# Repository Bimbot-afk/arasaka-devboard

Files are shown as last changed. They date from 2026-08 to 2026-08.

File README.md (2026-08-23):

# Arasaka DevBoard

A custom development board hardware project designed in KiCad.
It has a cool design based on Arasaka from Cyberpunk 2077 >:D

## Hardware Specifications & BOM

The board is built around the RP2040 ecosystem using high-density SMD components (mostly 0402 imperial footprint).

*   **Microcontroller (MCU):** Raspberry Pi RP2040 (Dual ARM Cortex-M0+ @ 133MHz, QFN-56)
*   **Storage:** Winbond W25Q128JVSIQ (16MB SPI Flash, SOIC-8)
*   **Power Management:** onsemi NCP1117ST33T3G (3.3V LDO Linear Regulator, SOT-223)
*   **Clock / Timing:** YXC 12MHz Crystal Oscillator (SMD 3225-4P)
*   **Interfacing:** Korean Hroparts TYPE-C-31-M-12 (USB-C Receptacle, 16-pin SMD)
*   **Electromechanical:** ALPS SKRKAEE020 (Tactile Switch for BOOTSEL/RESET)
*   **Passives:** Standard 0402 and 0603 ceramic capacitors (X5R/X7R dielectrics) and thick film resistors (1% tolerance on USB data lines).
*   **Expansion:** 2.54mm pitch through-hole pin headers.

## Schematics

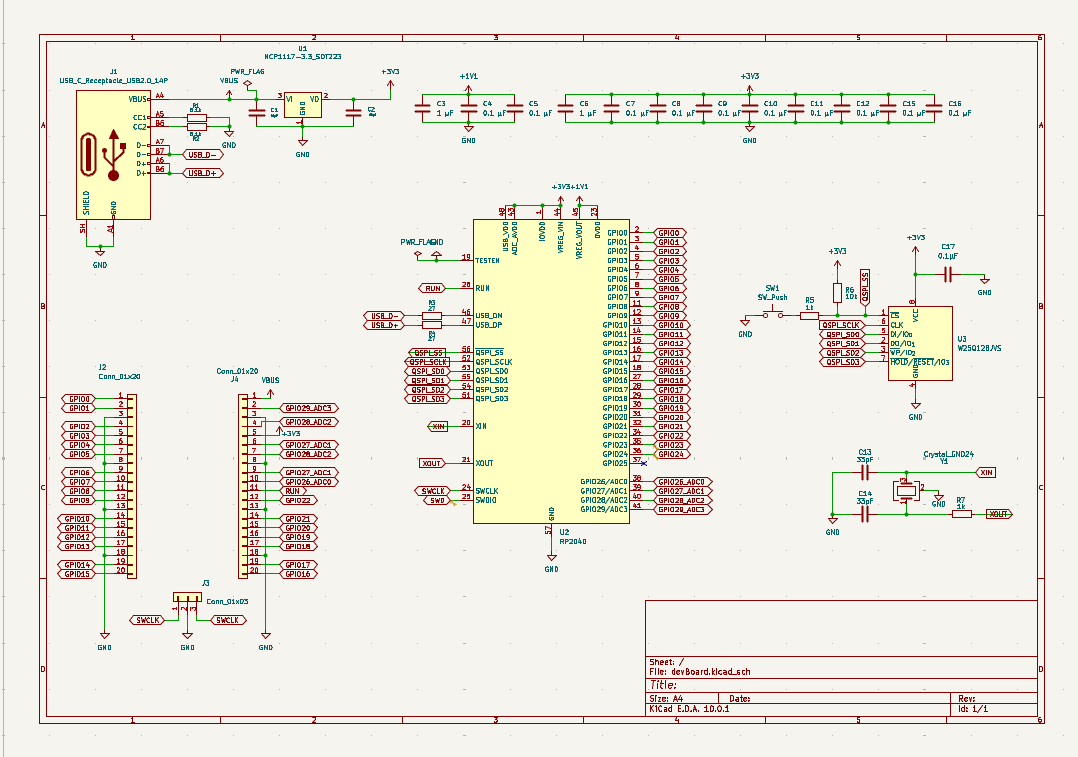
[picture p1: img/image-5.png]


## Layers

### F.cu

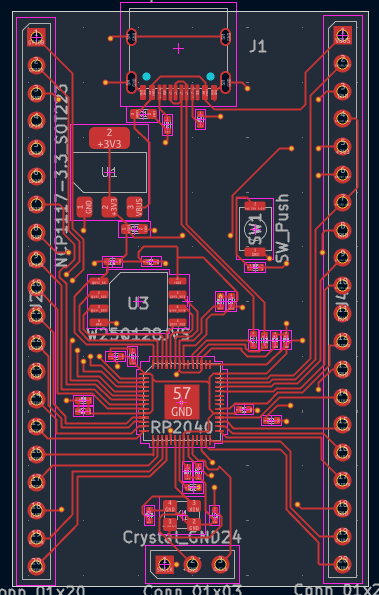
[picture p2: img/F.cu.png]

### B.cu

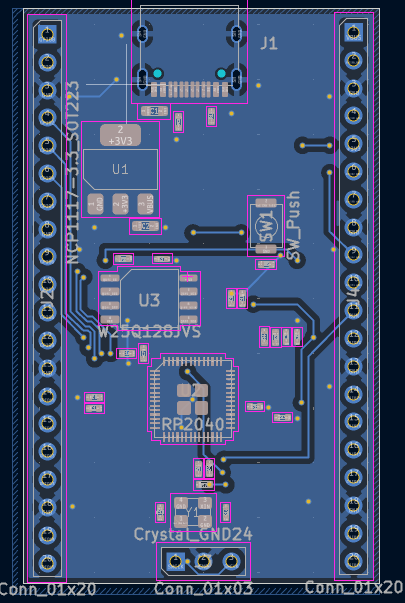
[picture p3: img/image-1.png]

### Both

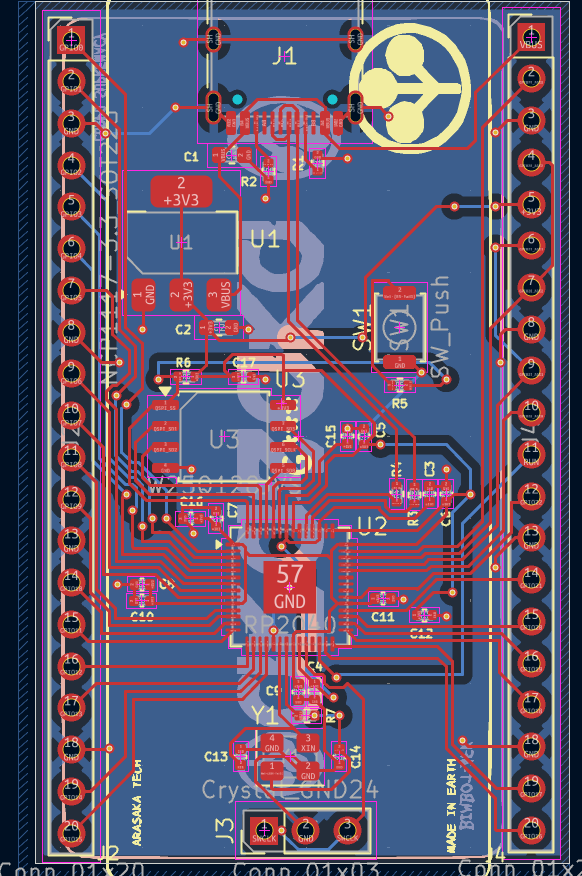
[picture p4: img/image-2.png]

### Front
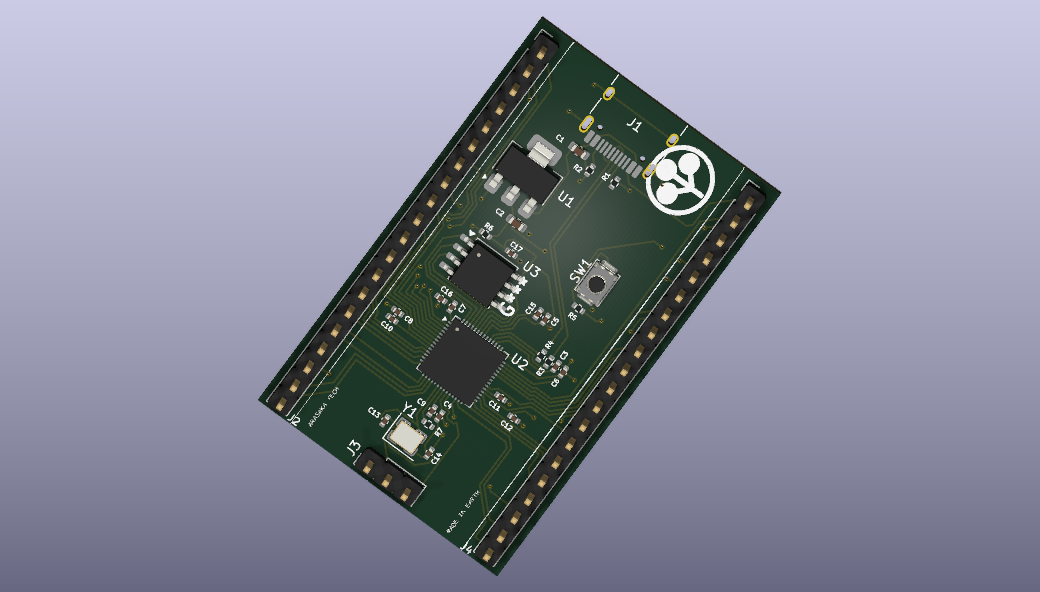
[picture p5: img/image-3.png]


### BACK
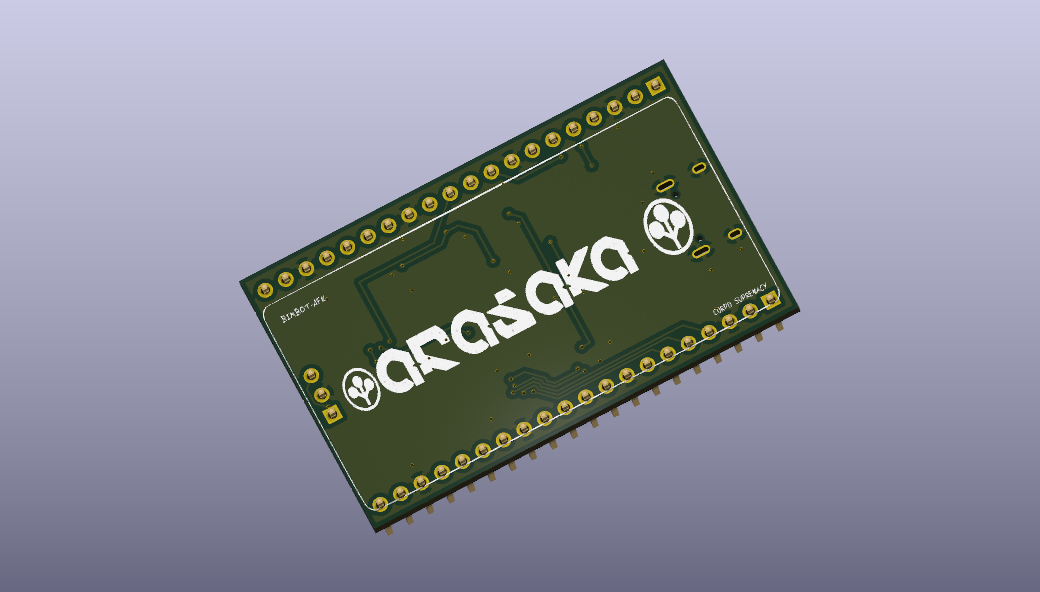
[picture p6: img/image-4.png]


## Project Structure

- **`3D_Models/`**: Contains 3D assets (`.step`, `.glb`, `.blend`) for the board and components.
- **`Fabrication/`**: Destination folder for generated manufacturing files like Gerbers, drill files, and BOMs.
- **`Libraries/`**: Project-specific footprints and symbols (e.g., custom Arasaka assets).
- **Core Files**: The main KiCad project files (`.kicad_pro`, `.kicad_sch`, `.kicad_pcb`) are located in the root directory.

## Getting Started

To view or modify this project, you will need [KiCad](https://www.kicad.org/) (Version 6+ recommended). 

1. Clone this repository.
2. Open the `devBoard.kicad_pro` file in KiCad to load the project.

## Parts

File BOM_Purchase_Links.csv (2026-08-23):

Designator | Value | Footprint | Quantity | Part Number | Purchase Link
C1, C2 | 10uF | 0603 | 2 | Generic 10uF 0603 | https://www.lcsc.com/search?q=10uF%200603%2010V
C3, C6 | 1uF | 0402 | 2 | Generic 1uF 0402 | https://www.lcsc.com/search?q=1uF%200402%2010V
C4, C5, C7, C8, C9, C10, C11, C12, C15, C16, C17 | 0.1uF | 0402 | 11 | Generic 0.1uF 0402 | https://www.lcsc.com/search?q=0.1uF%200402%2016V
C13, C14 | 33pF | 0402 | 2 | Generic 33pF 0402 | https://www.lcsc.com/search?q=33pF%200402%2050V
J1 | USB-C 16-pin | TYPE-C-31-M-12 | 1 | HRO TYPE-C-31-M-12 | https://www.lcsc.com/product-detail/USB-Connectors_HRO-Han-Run-TYPE-C-31-M-12_C165948.html
J2, J4 | Header 1x20 | 2.54mm Vertical | 2 | Generic 1x20 Pin Header | https://www.lcsc.com/search?q=1x20%20pin%20header%202.54mm
J3 | Header 1x3 | 2.54mm Vertical | 1 | Generic 1x3 Pin Header | https://www.lcsc.com/search?q=1x3%20pin%20header%202.54mm
R1, R2 | 5.1k | 0402 | 2 | Generic 5.1k 1% 0402 | https://www.lcsc.com/search?q=5.1k%200402%201%25
R3, R4 | 27R | 0402 | 2 | Generic 27R 1% 0402 | https://www.lcsc.com/search?q=27R%200402%201%25
R5, R7 | 1k | 0402 | 2 | Generic 1k 1% 0402 | https://www.lcsc.com/search?q=1k%200402%201%25
R6 | 10k | 0402 | 1 | Generic 10k 1% 0402 | https://www.lcsc.com/search?q=10k%200402%201%25
SW1 | Tactile Switch | ALPS SKRK | 1 | ALPS SKRKAEE020 | https://www.lcsc.com/product-detail/Tactile-Switches_ALPS-Alpine-SKRKAEE020_C139797.html
U1 | 3.3V LDO | SOT-223 | 1 | NCP1117ST33T3G | https://www.lcsc.com/product-detail/Linear-Voltage-Regulators-LDO_onsemi-NCP1117ST33T3G_C6186.html
U2 | RP2040 MCU | QFN-56 | 1 | Raspberry Pi RP2040 | https://www.lcsc.com/product-detail/Microcontroller-Units-MCUs-MPUs-SOCs_Raspberry-Pi-RP2040_C2040.html
U3 | 16MB Flash | SOIC-8 | 1 | W25Q128JVSIQ | https://www.lcsc.com/product-detail/NOR-FLASH_Winbond-Elec-W25Q128JVSIQ_C97521.html
Y1 | 12MHz Crystal | SMD 3225 | 1 | 12MHz 18pF 3225 | https://www.lcsc.com/product-detail/SMD-Crystal-Resonators_Yangxing-Tech-X322512MSB4GI_C13738.html

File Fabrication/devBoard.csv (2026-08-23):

Id | Identificador | Huella | Cantidad | Identificación | Suministrador y ref
1 | C1, C2 | C_0603_1608Metric | 2 | 10μF
2 | C3, C6 | C_0402_1005Metric | 2 | 1 μF
3 | C4, C5, C7, C8, C9, C10, C11, C12, C15, C16 | C_0402_1005Metric | 10 | 0,1 μF
4 | C13, C14 | C_0402_1005Metric | 2 | 33pF
5 | C17 | C_0402_1005Metric | 1 | 0.1µF
6 | J1 | USB_C_Receptacle_HRO_TYPE-C-31-M-12 | 1 | USB_C_Receptacle_USB2.0_14P
7 | J2, J4 | PinHeader_1x20_P2.54mm_Vertical | 2 | Conn_01x20
8 | J3 | PinHeader_1x03_P2.54mm_Vertical | 1 | Conn_01x03
9 | R1, R2 | R_0402_1005Metric | 2 | 5.1k
10 | R3, R4 | R_0402_1005Metric | 2 | 27
11 | R5, R7 | R_0402_1005Metric | 2 | 1k
12 | R6 | R_0402_1005Metric | 1 | 10k
13 | SW1 | SW_Push_SPST_NO_Alps_SKRK | 1 | SW_Push
14 | U1 | SOT-223-3_TabPin2 | 1 | NCP1117-3.3_SOT223
15 | U2 | QFN-56-1EP_7x7mm_P0.4mm_EP3.2x3.2mm | 1 | RP2040
16 | U3 | SOIC-8_5.3x5.3mm_P1.27mm | 1 | W25Q128JVS
17 | Y1 | Crystal_SMD_3225-4Pin_3.2x2.5mm | 1 | Crystal_GND24

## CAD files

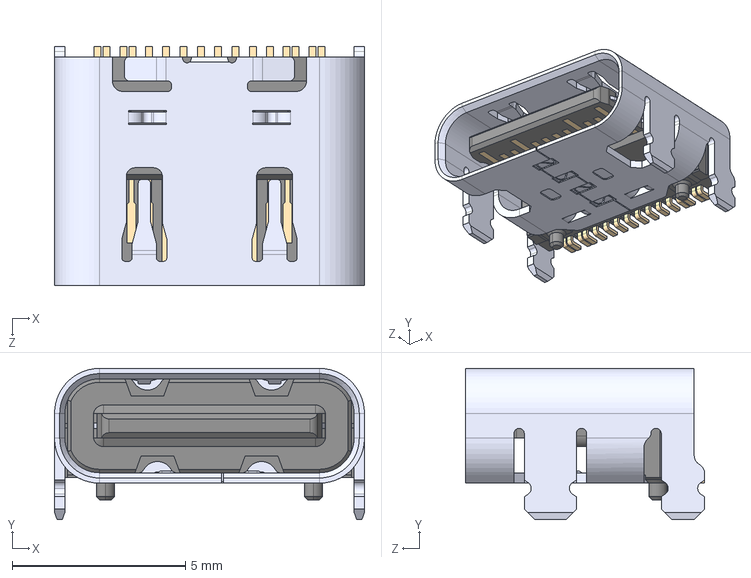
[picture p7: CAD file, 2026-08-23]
3D_Models/DX07S016JA1R1500--3DModel-STEP-269445.STEP
8.94 x 4.36 x 6.90 mm

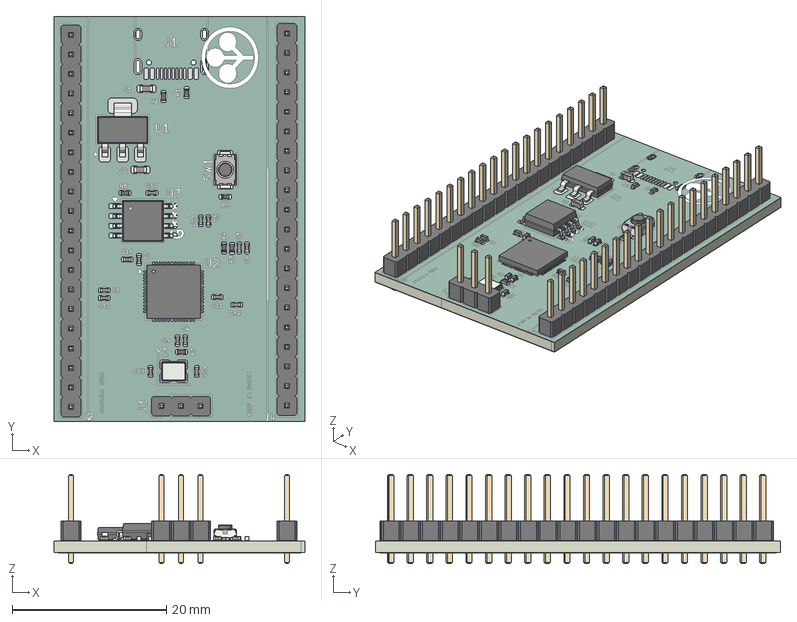
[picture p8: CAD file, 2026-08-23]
3D_Models/devBoard.step
32.5 x 52.5 x 11.5 mm
C_0402_1005Metric x 15
SOT-223
Crystal_SMD_3225-4Pin_3.2x2.5mm
R_0402_1005Metric x 7
C_0603_1608Metric x 2
SW_Push_SPST_NO_Alps_SKRK
PinHeader_1x20_P2.54mm_Vertical x 2
SOIC-8_5.3x5.3mm_P1.27mm
PinHeader_1x03_P2.54mm_Vertical
QFN-56-1EP_7x7mm_P0.4mm_EP3.2x3.2mm
devBoard_copper
devBoard_pad
devBoard_via
devBoard_silkscreen x 2
devBoard_soldermask x 2
devBoard_PCB

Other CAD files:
3D_Models/DevBoard.blend

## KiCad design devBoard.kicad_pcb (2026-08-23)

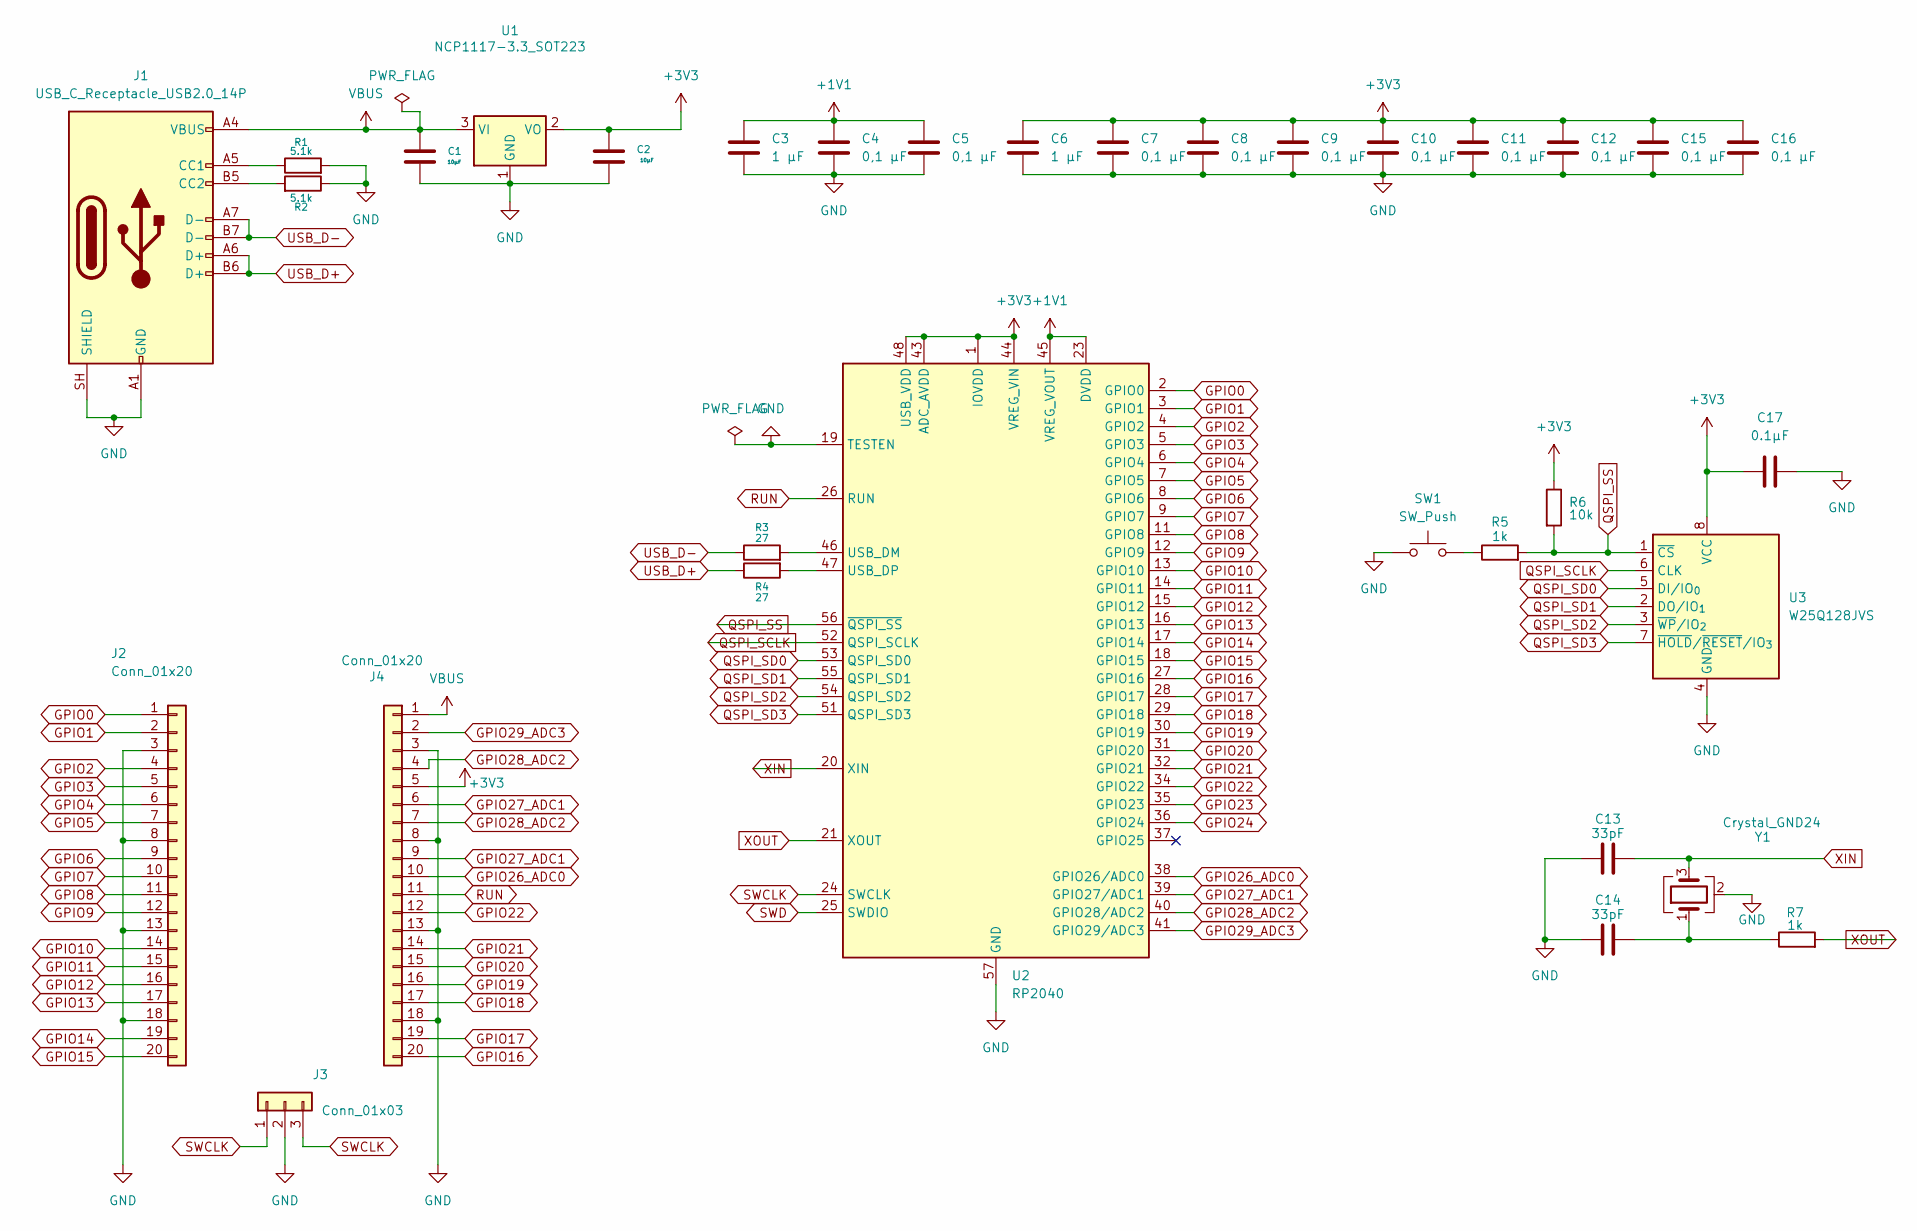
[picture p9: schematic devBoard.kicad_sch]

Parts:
C1, C2: 10μF; C_0603_1608Metric
C3, C6: 1 μF; C_0402_1005Metric
C4, C5, C7, C8, C9, C10, C11, C12, C15, C16: 0,1 μF; C_0402_1005Metric
C13, C14: 33pF; C_0402_1005Metric
C17: 0.1µF; C_0402_1005Metric
J1: USB_C_Receptacle_USB2.0_14P; USB_C_Receptacle_HRO_TYPE-C-31-M-12
J2, J4: Conn_01x20; PinHeader_1x20_P2.54mm_Vertical
J3: Conn_01x03; PinHeader_1x03_P2.54mm_Vertical
R1, R2: 5.1k; R_0402_1005Metric
R3, R4: 27; R_0402_1005Metric
R5, R7: 1k; R_0402_1005Metric
R6: 10k; R_0402_1005Metric
SW1: SW_Push; SW_Push_SPST_NO_Alps_SKRK
U1: NCP1117-3.3_SOT223; SOT-223-3_TabPin2
U2: RP2040; QFN-56-1EP_7x7mm_P0.4mm_EP3.2x3.2mm
U3: W25Q128JVS; SOIC-8_5.3x5.3mm_P1.27mm
Y1: Crystal_GND24; Crystal_SMD_3225-4Pin_3.2x2.5mm

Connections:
+1V1: C3.1, C4.1, C5.1, U2.23 (DVDD), U2.45 (VREG_VOUT), U2.50 (DVDD)
+3V3: C2.1, C6.1, C7.1, C8.1, C9.1, C10.1, C11.1, C12.1, C15.1, C16.1, C17.1, J4.5, R6.1, U1.2 (VO), U2.1 (IOVDD), U2.10 (IOVDD), U2.22 (IOVDD), U2.33 (IOVDD), U2.42 (IOVDD), U2.43 (ADC_AVDD), U2.44 (VREG_VIN), U2.48 (USB_VDD), U2.49 (IOVDD), U3.8 (VCC)
GND: C1.2, C2.2, C3.2, C4.2, C5.2, C6.2, C7.2, C8.2, C9.2, C10.2, C11.2, C12.2, C13.1, C14.1, C15.2, C16.2, C17.2, J1.A1 (GND), J1.A12 (GND), J1.B1 (GND), J1.B12 (GND), J1.SH (SHIELD), J2.3, J2.8, J2.13, J2.18, J3.2, J4.3, J4.8, J4.13, J4.18, R1.2, R2.1, SW1.1, U1.1 (GND), U2.19 (TESTEN), U2.57 (GND), U3.4 (GND), Y1.2 (G), Y1.4 (G)
GPIO0: J2.1, U2.2 (GPIO0)
GPIO1: J2.2, U2.3 (GPIO1)
GPIO2: J2.4, U2.4 (GPIO2)
GPIO3: J2.5, U2.5 (GPIO3)
GPIO4: J2.6, U2.6 (GPIO4)
GPIO5: J2.7, U2.7 (GPIO5)
GPIO6: J2.9, U2.8 (GPIO6)
GPIO7: J2.10, U2.9 (GPIO7)
GPIO8: J2.11, U2.11 (GPIO8)
GPIO9: J2.12, U2.12 (GPIO9)
GPIO10: J2.14, U2.13 (GPIO10)
GPIO11: J2.15, U2.14 (GPIO11)
GPIO12: J2.16, U2.15 (GPIO12)
GPIO13: J2.17, U2.16 (GPIO13)
GPIO14: J2.19, U2.17 (GPIO14)
GPIO15: J2.20, U2.18 (GPIO15)
GPIO16: J4.20, U2.27 (GPIO16)
GPIO17: J4.19, U2.28 (GPIO17)
GPIO18: J4.17, U2.29 (GPIO18)
GPIO19: J4.16, U2.30 (GPIO19)
GPIO20: J4.15, U2.31 (GPIO20)
GPIO21: J4.14, U2.32 (GPIO21)
GPIO22: J4.12, U2.34 (GPIO22)
GPIO23: U2.35 (GPIO23)
GPIO24: U2.36 (GPIO24)
GPIO26_ADC0: J4.10, U2.38 (GPIO26/ADC0)
GPIO27_ADC1: J4.6, J4.9, U2.39 (GPIO27/ADC1)
GPIO28_ADC2: J4.4, J4.7, U2.40 (GPIO28/ADC2)
GPIO29_ADC3: J4.2, U2.41 (GPIO29/ADC3)
unnamed: C14.2, R7.1, Y1.1
unnamed: J1.A5 (CC1), R1.1
unnamed: J1.B5 (CC2), R2.2
unnamed: R5.1, SW1.2
unnamed: R3.2, U2.46 (USB_DM)
unnamed: R4.2, U2.47 (USB_DP)
QSPI_SCLK: U2.52 (QSPI_SCLK), U3.6 (CLK)
QSPI_SD0: U2.53 (QSPI_SD0), U3.5 (DI/IO_{0})
QSPI_SD1: U2.55 (QSPI_SD1), U3.2 (DO/IO_{1})
QSPI_SD2: U2.54 (QSPI_SD2), U3.3 (~WP/IO_{2})
QSPI_SD3: U2.51 (QSPI_SD3), U3.7 (~HOLD/~RESET/IO_{3})
QSPI_SS: R5.2, R6.2, U2.56 (~QSPI_SS), U3.1 (~CS)
RUN: J4.11, U2.26 (RUN)
SWCLK: J3.1, J3.3, U2.24 (SWCLK)
SWD: U2.25 (SWDIO)
USB_D+: J1.A6 (D+), J1.B6 (D+), R4.1
USB_D-: J1.A7 (D-), J1.B7 (D-), R3.1
VBUS: C1.1, J1.A4 (VBUS), J1.A9 (VBUS), J1.B4 (VBUS), J1.B9 (VBUS), J4.1, U1.3 (VI)
XIN: C13.2, U2.20 (XIN), Y1.3
XOUT: R7.2, U2.21 (XOUT)

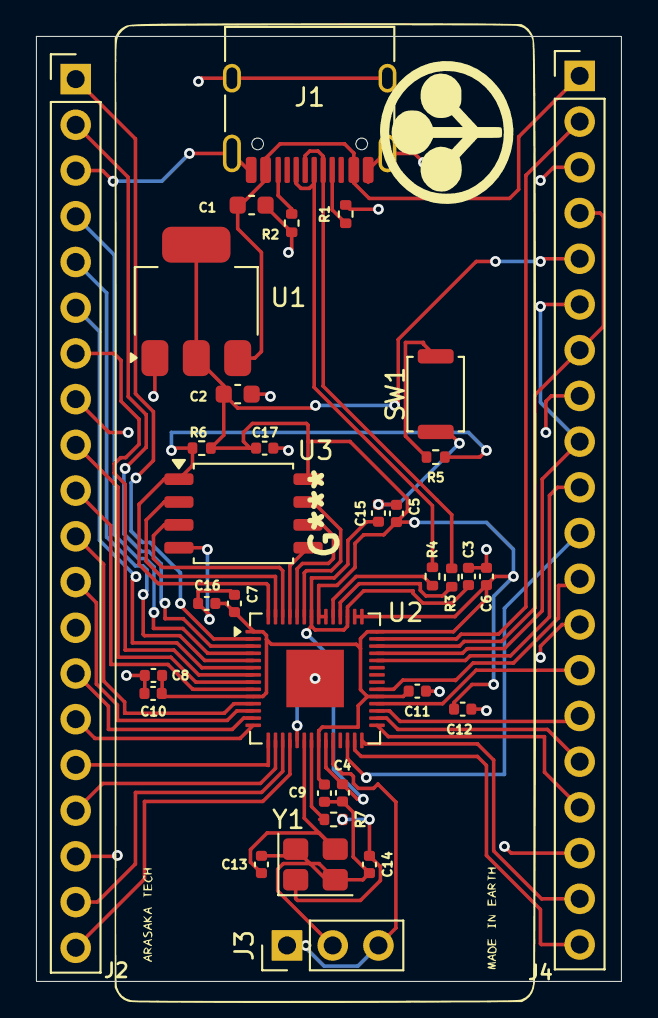
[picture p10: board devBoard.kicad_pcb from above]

Board: 2 copper layers, 32.5 x 52.5 mm, 33 parts (0 on the bottom side), 49 nets.

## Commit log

2026-08-23 Initial commit: clean folder structure, KiCad files, and README
    [DX07S016JA1R1500--3DModel-STEP-269445.STEP, DevBoard.blend, devBoard.csv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]
2026-08-23 Add BOM with purchase links and Gerbers ZIP export
    [BOM_Purchase_Links.csv]
2026-08-23 Move BOM and Gerbers to root directory for visibility
    [BOM_Purchase_Links.csv]
